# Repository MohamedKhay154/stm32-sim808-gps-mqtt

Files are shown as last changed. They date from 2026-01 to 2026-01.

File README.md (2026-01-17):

# GPS Tracker Using STM32 and SIM808

Embedded IoT tracker based on STM32 and SIM808, providing
GPS positioning, SMS control, and MQTT communication with
a Node-RED backend.

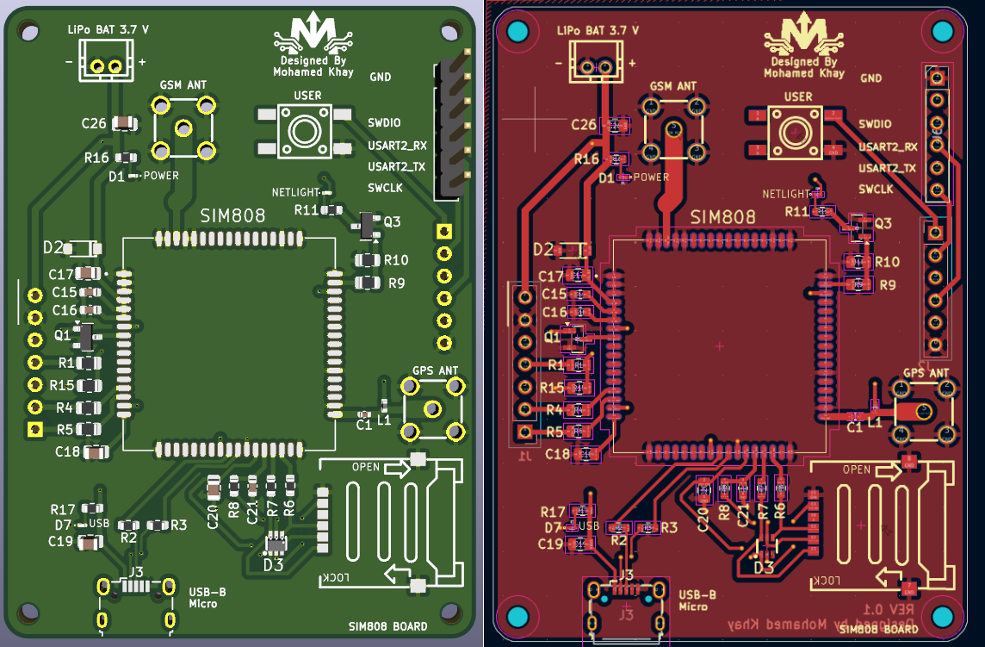
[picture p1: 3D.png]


## Features
- GPS position acquisition (SIM808)
- SMS send / receive
- MQTT communication over GPRS
- Node-RED dashboard integration
- Custom PCB design

## Repository Structure
stm32-sim808-gps-mqtt/

├── firmware/     STM32CubeIDE project

├── PCB Design/   PCB schematics and layout

├── Node-Red/     Node-RED flows and dashboard

├── Docs/         Documentation

├── Images/       Pictures

## System Overview

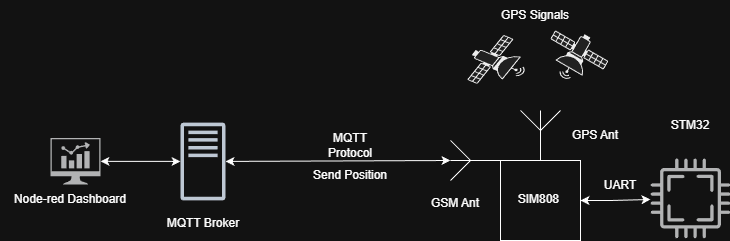
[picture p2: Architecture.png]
Architecture


The STM32 communicates with the SIM808 module via UART.
GPS data is parsed on the MCU and sent either via SMS or
published to an MQTT broker over GPRS. Node-RED processes
incoming data and provides visualization and control.

## PCB Design

The PCB design is divided into two separate boards:

1.One board for the STM32 MCU

2.One board for the SIM808 module

These boards are stacked on top of each other using a common connector interface.

# SIM808 
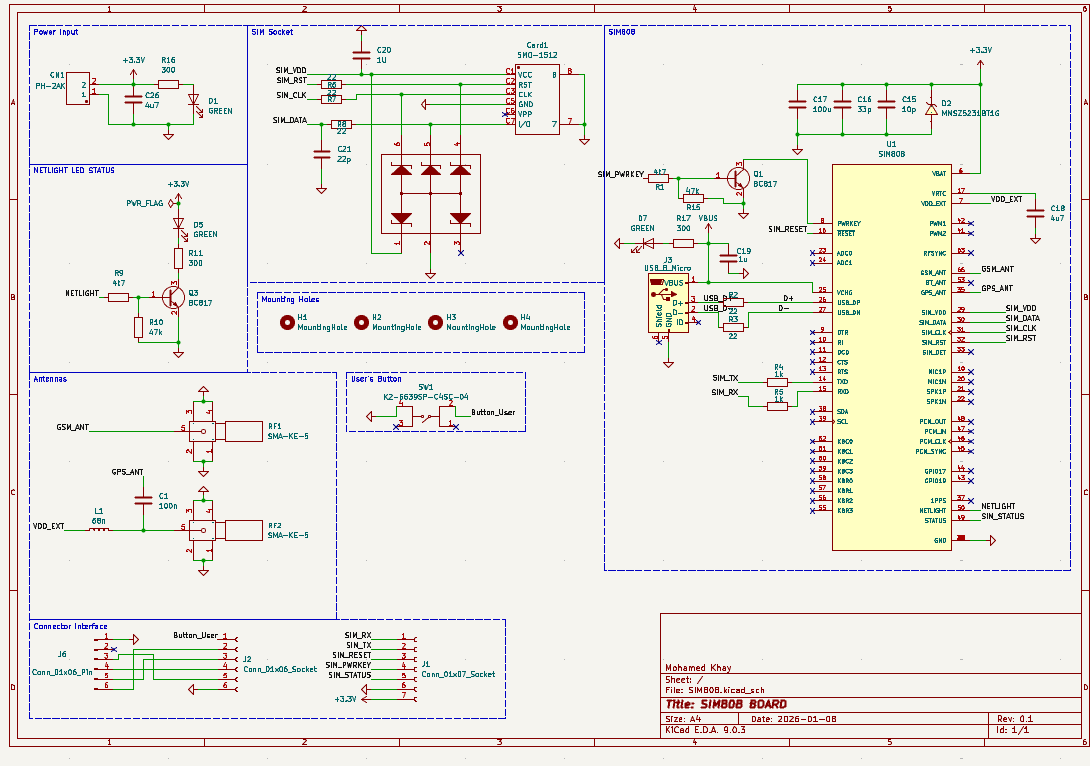
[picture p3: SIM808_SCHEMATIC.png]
SIM808 SCHEMATIC

Notes:

The board uses a LiPo battery as the main power source. The SIM808 module includes an internal charging circuit accessible via USB.

According to the datasheet, when powering the system with a LiPo battery, no additional voltage regulator is needed, provided the battery delivers 3.7 V nominal and 2 A peak.

Both the GPS and GSM antennas require 50 Ω impedance traces and should be placed as close as possible to the module for optimal signal performance.

# STM32 
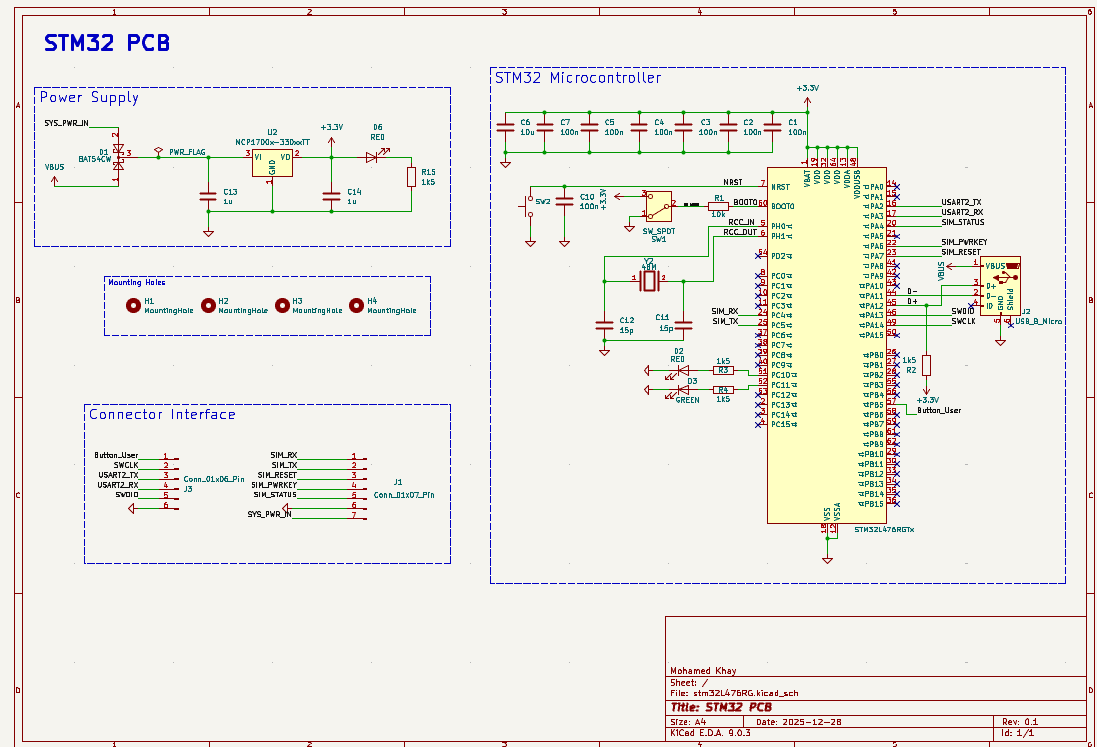
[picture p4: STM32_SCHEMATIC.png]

Notes:

The board uses an MCP1700 voltage regulator to provide stable 3.3 V to the STM32.

There are two power inputs:

1.USB

2.Power from the SIM808 board via a dedicated connector

A Schottky diode is used to prevent backflow and protect the STM32 when multiple power sources are connected.

## Firmware Design

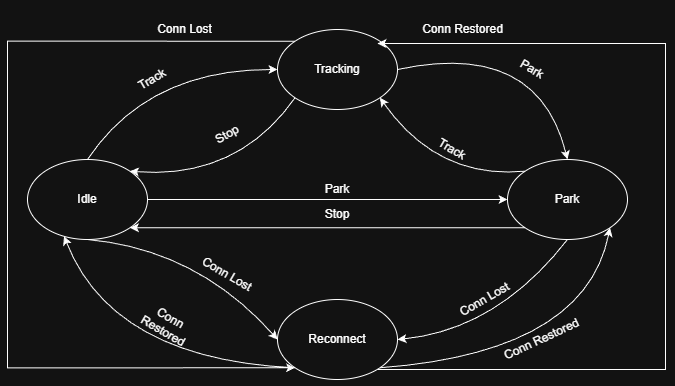
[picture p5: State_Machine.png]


The firmware is structured around a finite state machine (FSM) to securely manage the different operational modes of the module:

- Idle: The module waits for incoming commands or triggers.

- Tracking: Begins continuous position tracking using a timer.

- Parking: Sends the current position and waits for either a “theft move” or “stop” command.

- Reconnect: At any state, if the module detects a disconnection, it transitions to the Reconnect state to re-establish the connection, then returns to the previous state.

Alongside the FSM, a watchdog timer monitors the connection every 30 seconds and attempts to reconnect if needed, ensuring reliable communication.

# Firmware Modules

* SIM808.c
Responsible for all SIM808 communications, including:

- Sending AT commands

- Parsing GPS data

- Handling message transmission and waiting for responses

* MQTT (mqtt.c / mqtt.h)
Implements the MQTT protocol using the Paho MQTT library, helping to build and send MQTT packets.

* tracker_fsm.c
Implements the state machine, including:

- Event handlers
- State transitions

## Node-RED Dashboard

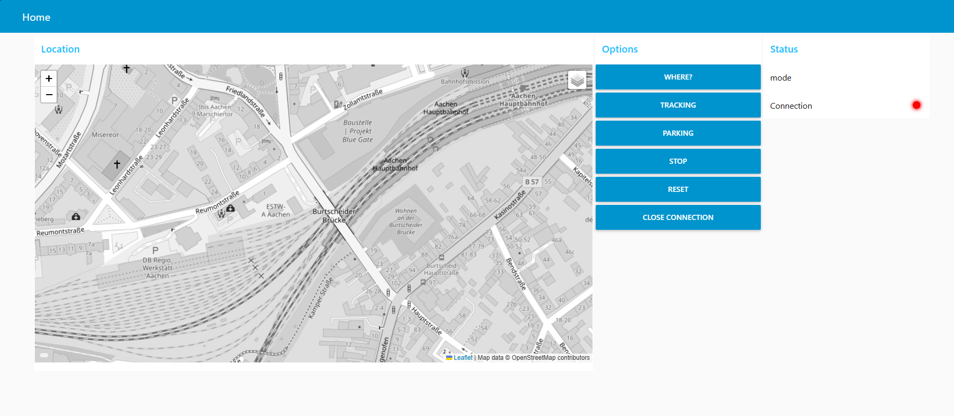
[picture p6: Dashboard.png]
Node Red Dashboard

The dashboard is built using Node-RED and a world map visualization.

Node-RED natively supports MQTT, so once the STM32 firmware publishes a position, the Node-RED flow (as a subscriber) receives it and displays it as a pointer on the map.

Since the system has multiple operational modes (continuous tracking, parking, etc.), a global variable tracks the current mode. This allows the dashboard to adjust the visualization accordingly:

Continuous tracking → plots the path as a line

Parking mode → shows a circle around the parked area

Commands are sent from the dashboard using buttons that publish messages to the MQTT broker. The SIM808 module on the device subscribes to these commands and acts accordingly.

## Further Notes

The project is still under development.

The source code is being updated and may change as new features are added or improvements are made.

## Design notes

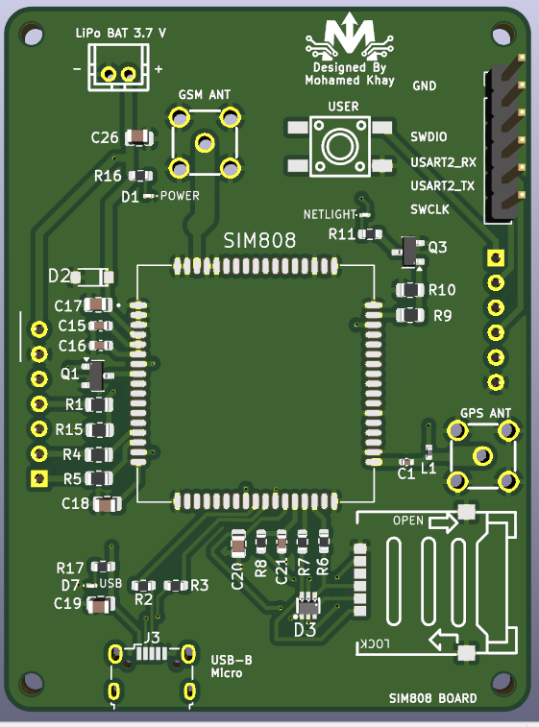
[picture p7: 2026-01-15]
Images/PCB/3D Top SIM808 Board.png

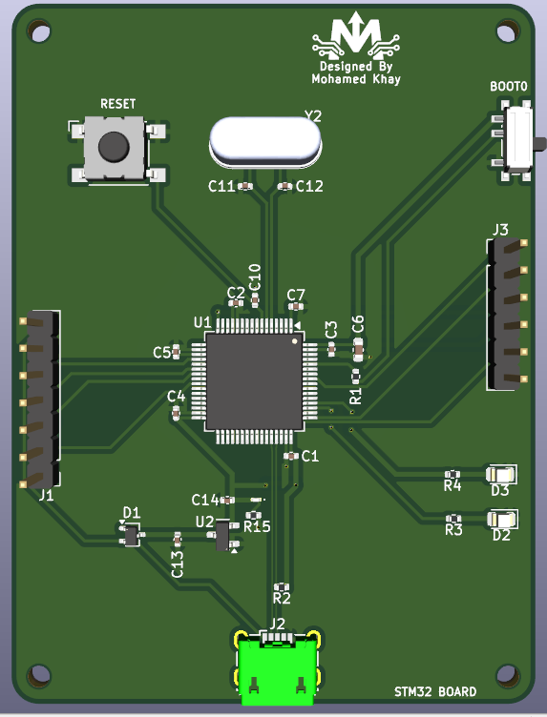
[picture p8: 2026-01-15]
Images/PCB/3D Top STM32 Board.png

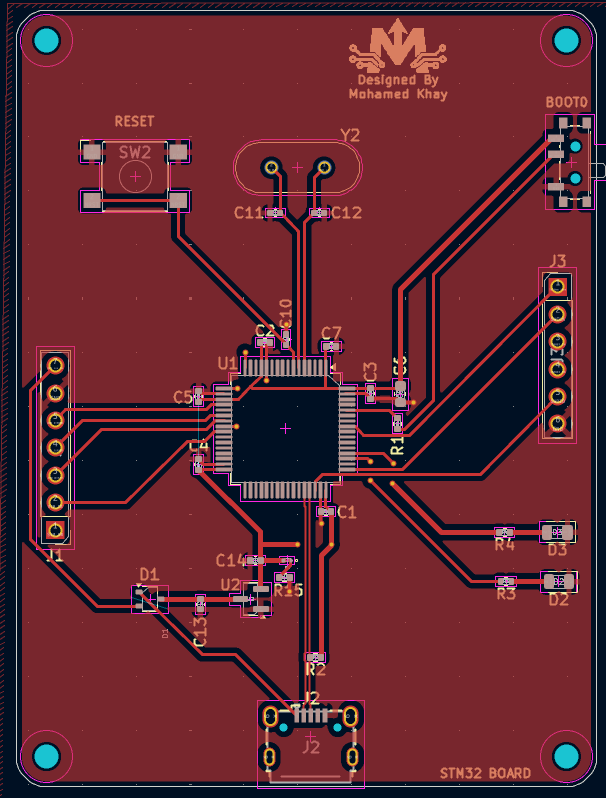
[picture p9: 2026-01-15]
Images/PCB/First Layer STM32 Board.png

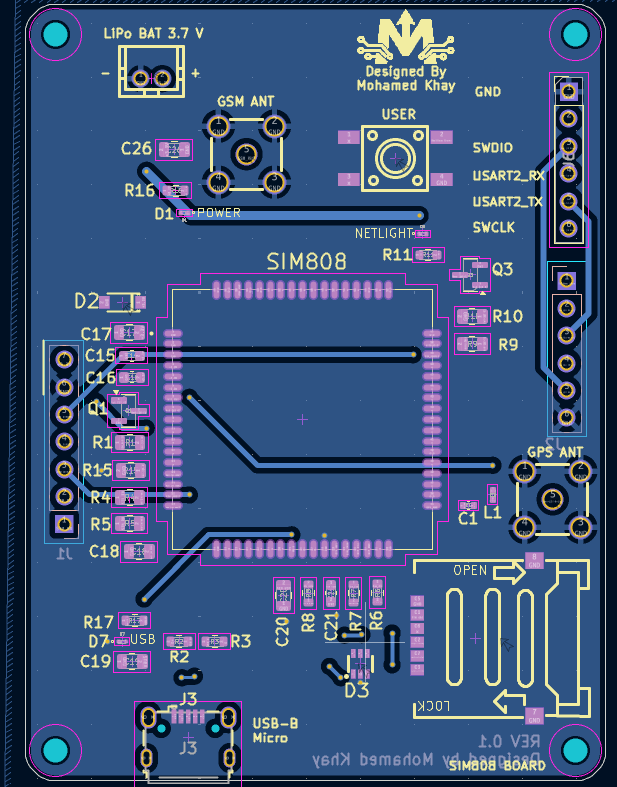
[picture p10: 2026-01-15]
Images/PCB/Second Layer SIM808 Board.png

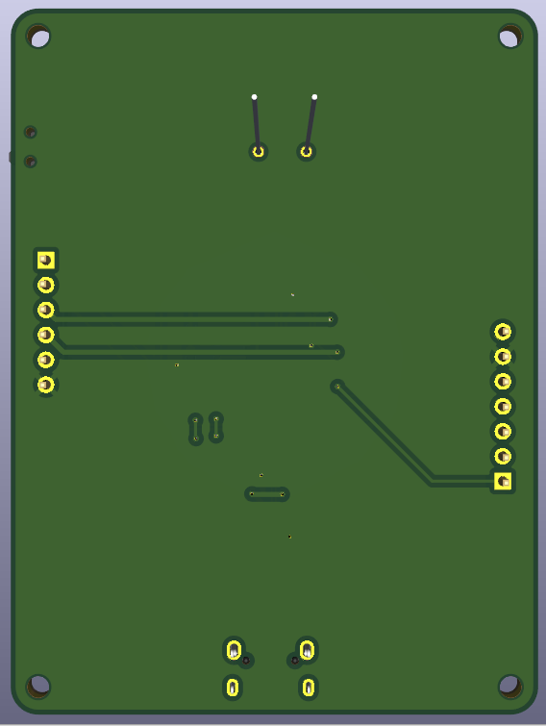
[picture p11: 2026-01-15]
Images/PCB/3D Bottom STM32 Board.png

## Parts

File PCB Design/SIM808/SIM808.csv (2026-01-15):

Reference | Qty | Value | DNP | Exclude from BOM | Exclude from Board | Footprint | Datasheet
C15 | 1 | 10p |  |  |  | Capacitor_SMD:C_0603_1608Metric | ~
C16 | 1 | 33p |  |  |  | Capacitor_SMD:C_0603_1608Metric | ~
C17 | 1 | 100u |  |  |  | Capacitor_SMD:C_0805_2012Metric | ~
C18,C26 | 2 | 4u7 |  |  |  | Capacitor_SMD:C_0805_2012Metric | ~
C19 | 1 | 1u |  |  |  | Capacitor_SMD:C_0805_2012Metric | ~
C20 | 1 | 1U |  |  |  | Capacitor_SMD:C_0805_2012Metric | ~
C21 | 1 | 22p |  |  |  | Capacitor_SMD:C_0603_1608Metric | ~
C22,C23,C24,C25 | 4 | 0 |  |  |  | Capacitor_SMD:C_0603_1608Metric | ~
Card1 | 1 | SMO-1512 |  |  |  | SIM808:SIM_SMD_SMO_1512
CN1 | 1 | JST-PH-2-SMT-RA |  |  |  | SIM808:CONN-SMD_JST-PH-2-SMT-RA
D1,D5,D7 | 3 | GREEN |  |  |  | LED_SMD:LED_0201_0603Metric | ~
D2,D3 | 2 | D_Zener |  |  |  | Diode_SMD:D_0603_1608Metric | ~
D4 | 1 | SMF12CT1G |  |  |  | SIM808:SMF12CT1G
D6 | 1 | MBR0520 |  |  |  | Diode_SMD:D_SOD-123 | http://www.mccsemi.com/up_pdf/MBR0520~MBR0580(SOD123).pdf
H1,H2,H3,H4 | 4 | MountingHole |  | Excluded from BOM |  | MountingHole:MountingHole_2.2mm_M2 | ~
J1 | 1 | Conn_01x07_Socket |  |  |  | Connector_PinSocket_2.54mm:PinSocket_1x07_P2.54mm_Vertical | ~
J2 | 1 | Conn_01x06_Socket |  |  |  | Connector_PinSocket_2.54mm:PinSocket_1x06_P2.54mm_Vertical | ~
J3 | 1 | USB_B_Micro |  |  |  | Connector_USB:USB_Micro-B_Wuerth_629105150521 | ~
J4,J5 | 2 | SMA_CONNECTOR |  |  |  | SMA_CONNECTOR:LPRS_SMA_CONNECTOR
J6 | 1 | Conn_01x06_Pin |  |  |  | Connector_PinHeader_2.54mm:PinHeader_1x06_P2.54mm_Vertical | ~
Q1,Q2 | 2 | 2N3904 |  |  |  | Package_TO_SOT_THT:TO-92_Inline | https://www.onsemi.com/pub/Collateral/2N3903-D.PDF
R1,R9 | 2 | 4k7 |  |  |  | Resistor_SMD:R_0805_2012Metric | ~
R2,R3,R6,R7,R8 | 5 | 22 |  |  |  | Resistor_SMD:R_0603_1608Metric | ~
R4,R5 | 2 | 1k |  |  |  | Resistor_SMD:R_0805_2012Metric | ~
R10,R15 | 2 | 47k |  |  |  | Resistor_SMD:R_0805_2012Metric | ~
R11,R16,R17 | 3 | 300 |  |  |  | Resistor_SMD:R_0603_1608Metric | ~
R12,R13,R14 | 3 | 0 |  |  |  | Resistor_SMD:R_0603_1608Metric | ~
SW1 | 1 | SW_Push |  |  |  | Button_Switch_THT:SW_PUSH_6mm | ~
U1 | 1 | SIM808 |  |  |  | SIM808 (1):XCVR_SIM808

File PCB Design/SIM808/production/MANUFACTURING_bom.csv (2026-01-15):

Designator | Footprint | Quantity | Value | LCSC Part #
C1 | 0402 | 1 | 100n
C15 | 0603 | 1 | 10p
C16 | 0603 | 1 | 33p
C17 | 0805 | 1 | 100u
C18, C26 | 0805 | 2 | 4u7
C19, C20 | 0805 | 2 | 1u
C21 | 0603 | 1 | 22p
CARD1 | SIM_SMD_SMO_1512 | 1 | SMO-1512
CN1 | CONN-TH_PH-2A | 1 | PH-2AK
D1, D5, D7 | 0201 | 3 | GREEN
D2 | SOD-123_L2.8-W1.8-LS3.7-RD | 1 | MMSZ5231BT1G
D3 | SMF12CT1G | 1 | SMF12CT1G
J1 | PinSocket_1x07_P2.54mm_Vertical | 1 | Conn_01x07_Socket
J2 | PinSocket_1x06_P2.54mm_Vertical | 1 | Conn_01x06_Socket
J3 | USB_Micro-B_Wuerth_629105150521 | 1 | USB_B_Micro
J6 | PinHeader_1x06_P2.54mm_Vertical | 1 | Conn_01x06_Pin
L1 | 0402 | 1 | 68n
Q1, Q3 | SOT-23 | 2 | BC817
R1, R9 | 0805 | 2 | 4k7
R10, R15 | 0805 | 2 | 47k
R11, R16, R17 | 0603 | 3 | 300
R2, R3, R6, R7, R8 | 0603 | 5 | 22
R4, R5 | 0805 | 2 | 1k
RF1, RF2 | SMA-TH_SMA-KE-5 | 2 | SMA-KE-5
SW1 | KEY-SMD_4P-L6.0-W6.0-P3.90-LS9.0 | 1 | K2-6639SP-C4SC-04
U1 | XCVR_SIM808 | 1 | SIM808

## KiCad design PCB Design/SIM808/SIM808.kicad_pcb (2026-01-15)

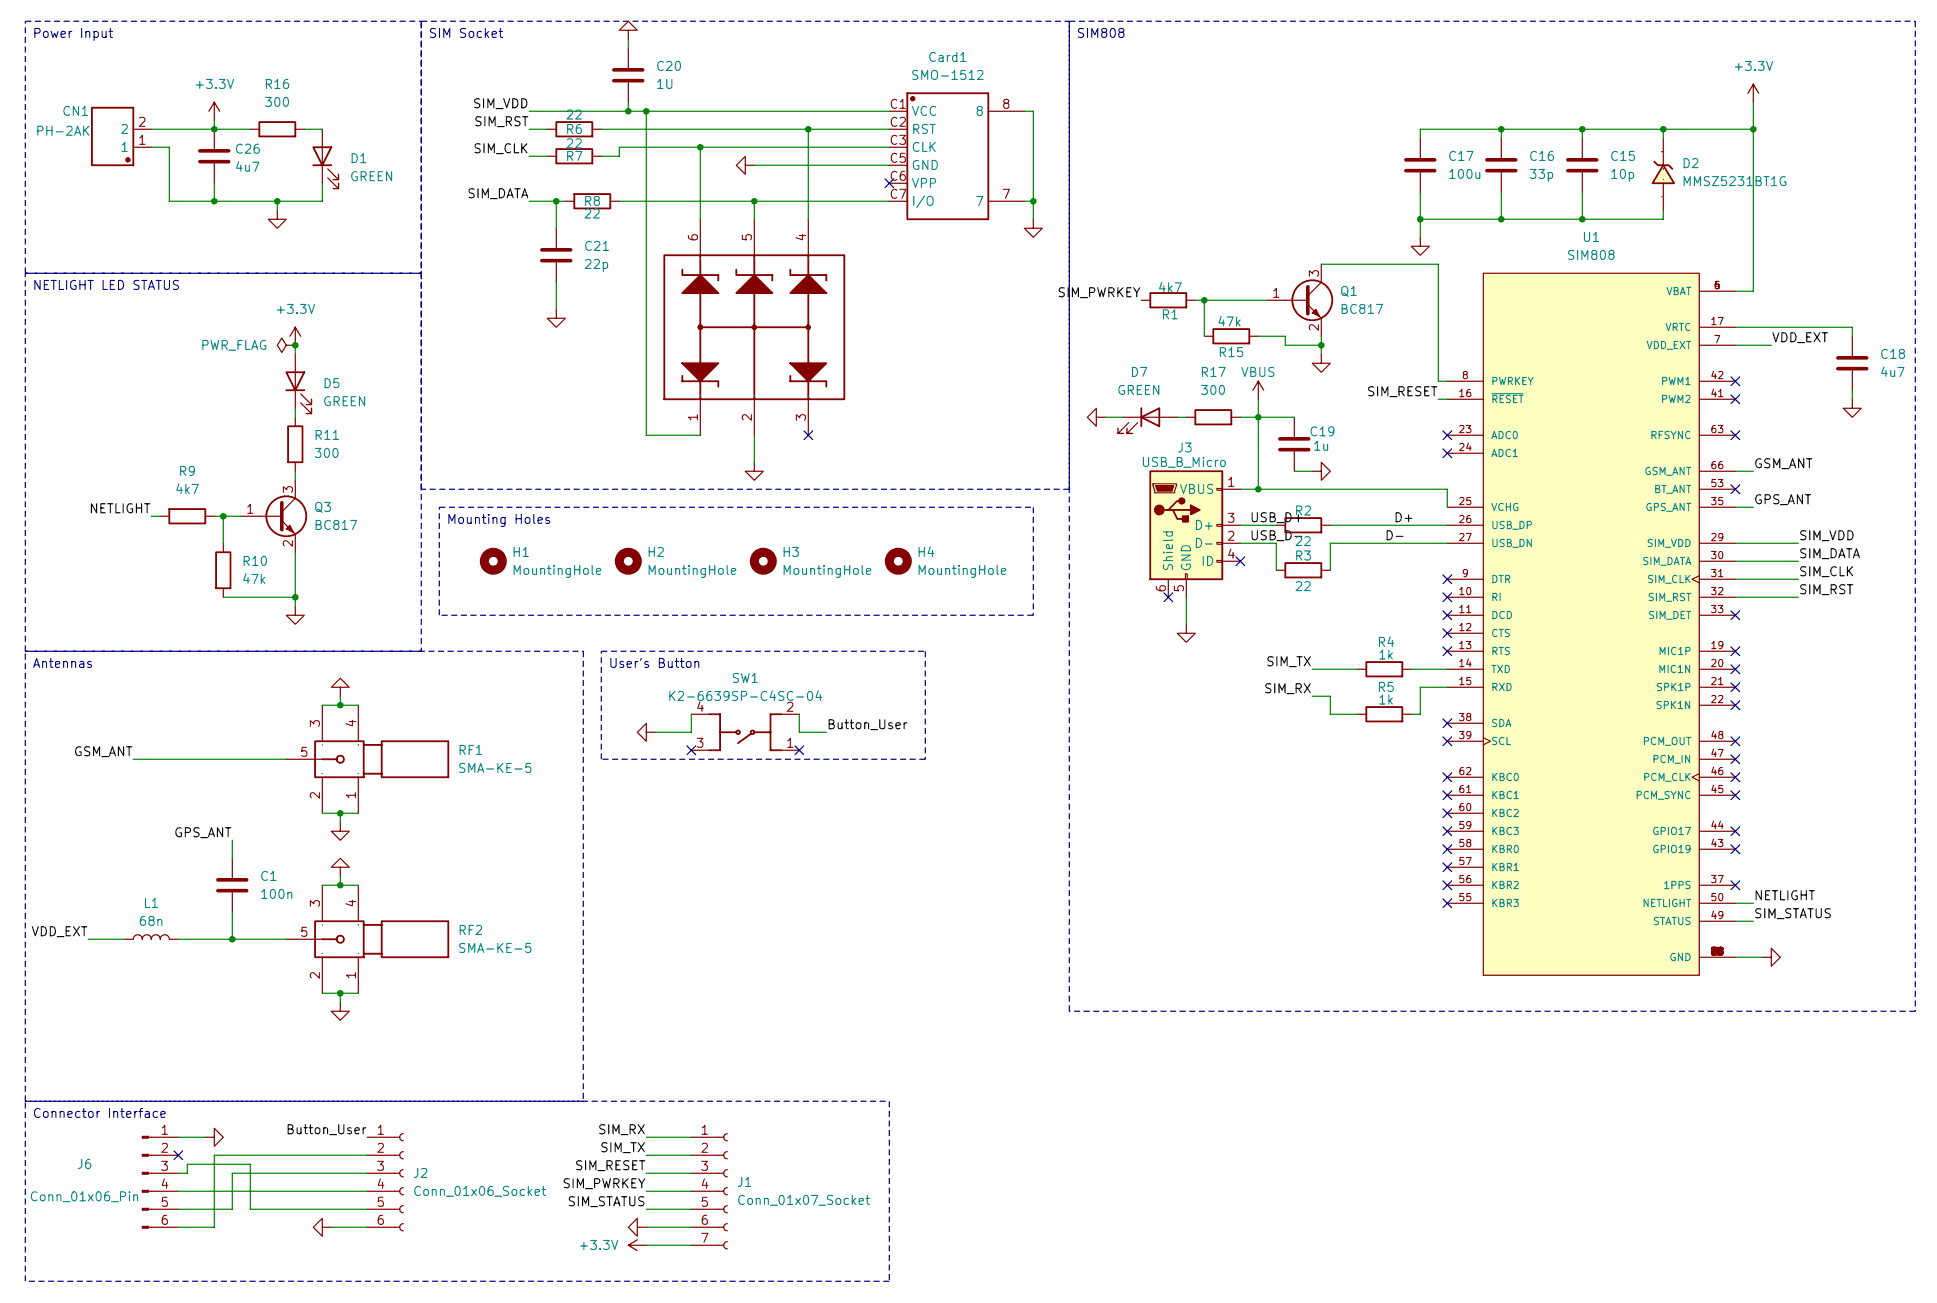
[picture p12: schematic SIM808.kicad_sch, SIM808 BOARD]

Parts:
C1: 100n; C_0402_1005Metric
C15: 10p; C_0603_1608Metric
C16: 33p; C_0603_1608Metric
C17: 100u; C_0805_2012Metric
C18, C26: 4u7; C_0805_2012Metric
C19: 1u; C_0805_2012Metric
C20: 1U; C_0805_2012Metric
C21: 22p; C_0603_1608Metric
CN1: PH-2AK; CONN-TH_PH-2A; Manufacturer Part PH-2AK
Card1: SMO-1512; SIM_SMD_SMO_1512; Manufacturer Part SMO-1512
D1, D5, D7: GREEN; LED_0201_0603Metric
D2: MMSZ5231BT1G; SOD-123_L2.8-W1.8-LS3.7-RD; Manufacturer Part MMSZ5231BT1G
D3: SMF12CT1G; Manufacturer Part SMF12CT1G
H1, H2, H3, H4: MountingHole; MountingHole_2.2mm_M2
J1: Conn_01x07_Socket; PinSocket_1x07_P2.54mm_Vertical
J2: Conn_01x06_Socket; PinSocket_1x06_P2.54mm_Vertical
J3: USB_B_Micro; USB_Micro-B_Wuerth_629105150521
J6: Conn_01x06_Pin; PinHeader_1x06_P2.54mm_Vertical
L1: 68n; L_0402_1005Metric
Q1, Q3: BC817; SOT-23
R1, R9: 4k7; R_0805_2012Metric
R2, R3, R6, R7, R8: 22; R_0603_1608Metric
R4, R5: 1k; R_0805_2012Metric
R10, R15: 47k; R_0805_2012Metric
R11, R16, R17: 300; R_0603_1608Metric
RF1, RF2: SMA-KE-5; SMA-TH_SMA-KE-5; Manufacturer Part SMA-KE-5
SW1: K2-6639SP-C4SC-04; KEY-SMD_4P-L6.0-W6.0-P3.90-LS9.0; Manufacturer Part K2-6639SP-C4SC-04
U1: SIM808; XCVR_SIM808; PARTREV 1.03

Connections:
+3.3V: C15.2, C16.2, C17.2, C26.2, CN1.2, D2.1 (K), D5.2 (A), J1.7, R16.1, U1.4 (VBAT), U1.5 (VBAT), U1.6 (VBAT)
/Button_User: J2.1, SW1.2
/D+: R2.2, U1.26 (USB_DP)
/D-: R3.2, U1.27 (USB_DN)
/GPS_ANT: C1.1, U1.35 (GPS_ANT)
/GSM_ANT: RF1.5, U1.66 (GSM_ANT)
/NETLIGHT: R9.2, U1.50 (NETLIGHT)
/SIM_CLK: R7.1, U1.31 (SIM_CLK)
/SIM_DATA: C21.1, R8.2, U1.30 (SIM_DATA)
/SIM_PWRKEY: J1.4, R1.1
/SIM_RESET: J1.3, U1.16 (~RESET)
/SIM_RST: R6.1, U1.32 (SIM_RST)
/SIM_RX: J1.1, R5.1
/SIM_STATUS: J1.5, U1.49 (STATUS)
/SIM_TX: J1.2, R4.1
/SIM_VDD: C20.2, Card1.C1 (VCC), D3.1, U1.29 (SIM_VDD)
/USB_D+: J3.3 (D+), R2.1
/USB_D-: J3.2 (D-), R3.1
/VDD_EXT: L1.1, U1.7 (VDD_EXT)
GND: C15.1, C16.1, C17.1, C18.1, C19.1, C20.1, C21.2, C26.1, CN1.1, Card1.7, Card1.8, Card1.C5 (GND), D1.1 (K), D2.2 (A), D3.2, D7.1 (K), J1.6, J2.6, J3.5 (GND), J6.1, Q1.2 (E), Q3.2 (E), R10.2, R15.2, RF1.1, RF1.2, RF1.3, RF1.4, RF2.1, RF2.2, RF2.3, RF2.4, SW1.4, U1.1 (GND), U1.2 (GND), U1.3 (GND), U1.18 (GND), U1.28 (GND), U1.34 (GND), U1.36 (GND), U1.40 (GND), U1.51 (GND), U1.52 (GND), U1.54 (GND), U1.64 (GND), U1.65 (GND), U1.67 (GND), U1.68 (GND)
unnamed: C1.2, L1.2, RF2.5
unnamed: Card1.C3 (CLK), D3.6, R7.2
unnamed: Card1.C7 (I/O), D3.5, R8.1
unnamed: Card1.C2 (RST), D3.4, R6.2
unnamed: D1.2 (A), R16.2
unnamed: D5.1 (K), R11.1
unnamed: D7.2 (A), R17.1
unnamed: J2.2, J6.6
unnamed: J2.3, J6.5
unnamed: J2.4, J6.4
unnamed: J2.5, J6.3
unnamed: Q1.1 (B), R1.2, R15.1
unnamed: Q1.3 (C), U1.8 (PWRKEY)
unnamed: Q3.1 (B), R9.1, R10.1
unnamed: Q3.3 (C), R11.2
unnamed: R5.2, U1.15 (RXD)
unnamed: R4.2, U1.14 (TXD)
unnamed: C18.2, U1.17 (VRTC)
VBUS: C19.2, J3.1 (VBUS), R17.2, U1.25 (VCHG)

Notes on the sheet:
User's Button
Mounting Holes
NETLIGHT LED STATUS
Connector Interface
Power Input
Antennas
SIM808
SIM Socket

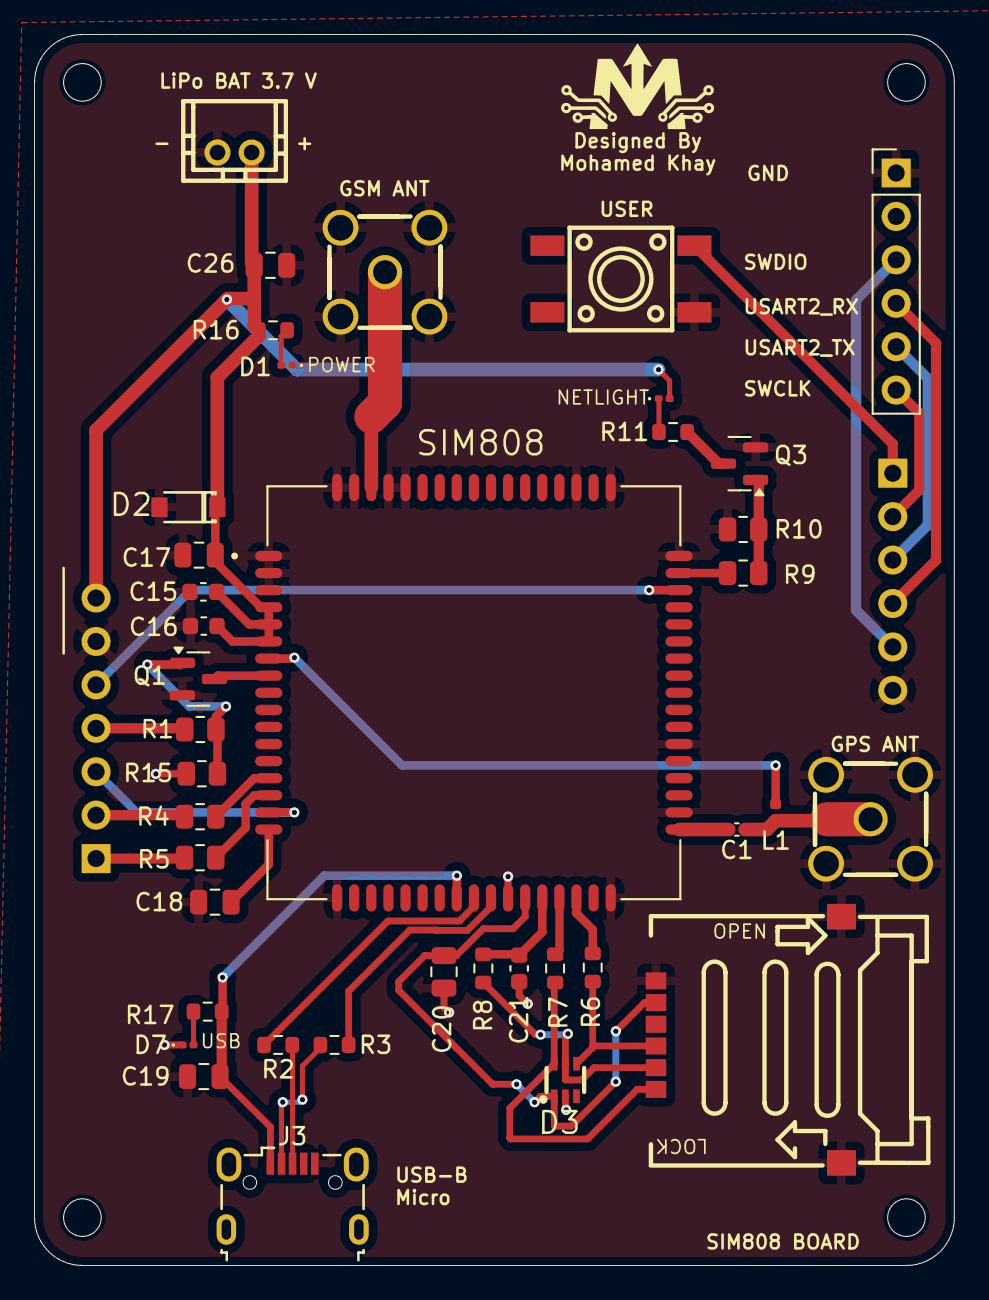
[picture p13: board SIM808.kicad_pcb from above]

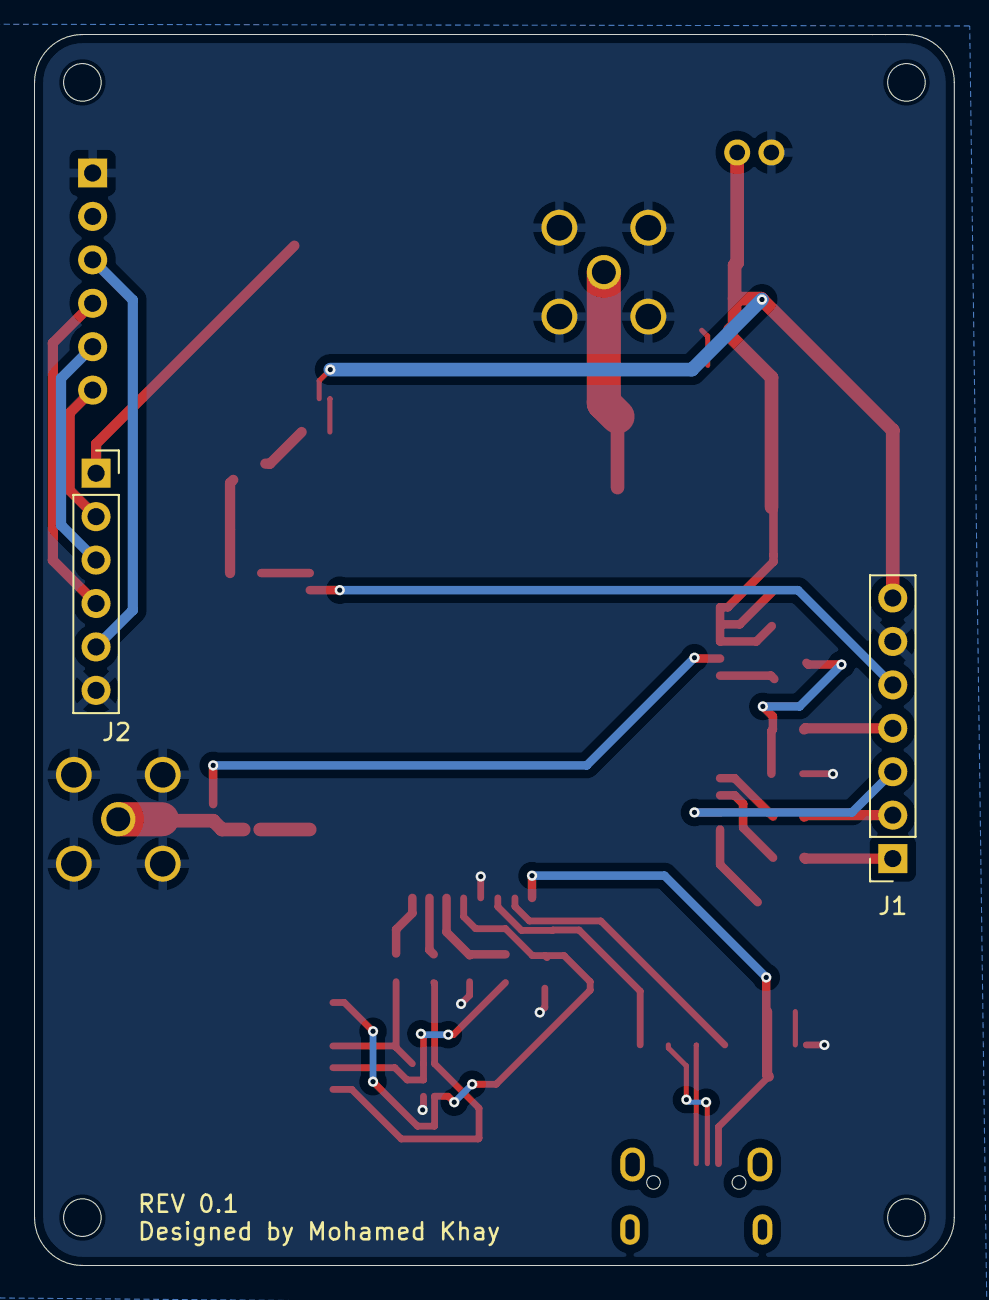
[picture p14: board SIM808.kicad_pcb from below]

Board: 2 copper layers, 53.8 x 72.0 mm, 45 parts (2 on the bottom side), 39 nets.

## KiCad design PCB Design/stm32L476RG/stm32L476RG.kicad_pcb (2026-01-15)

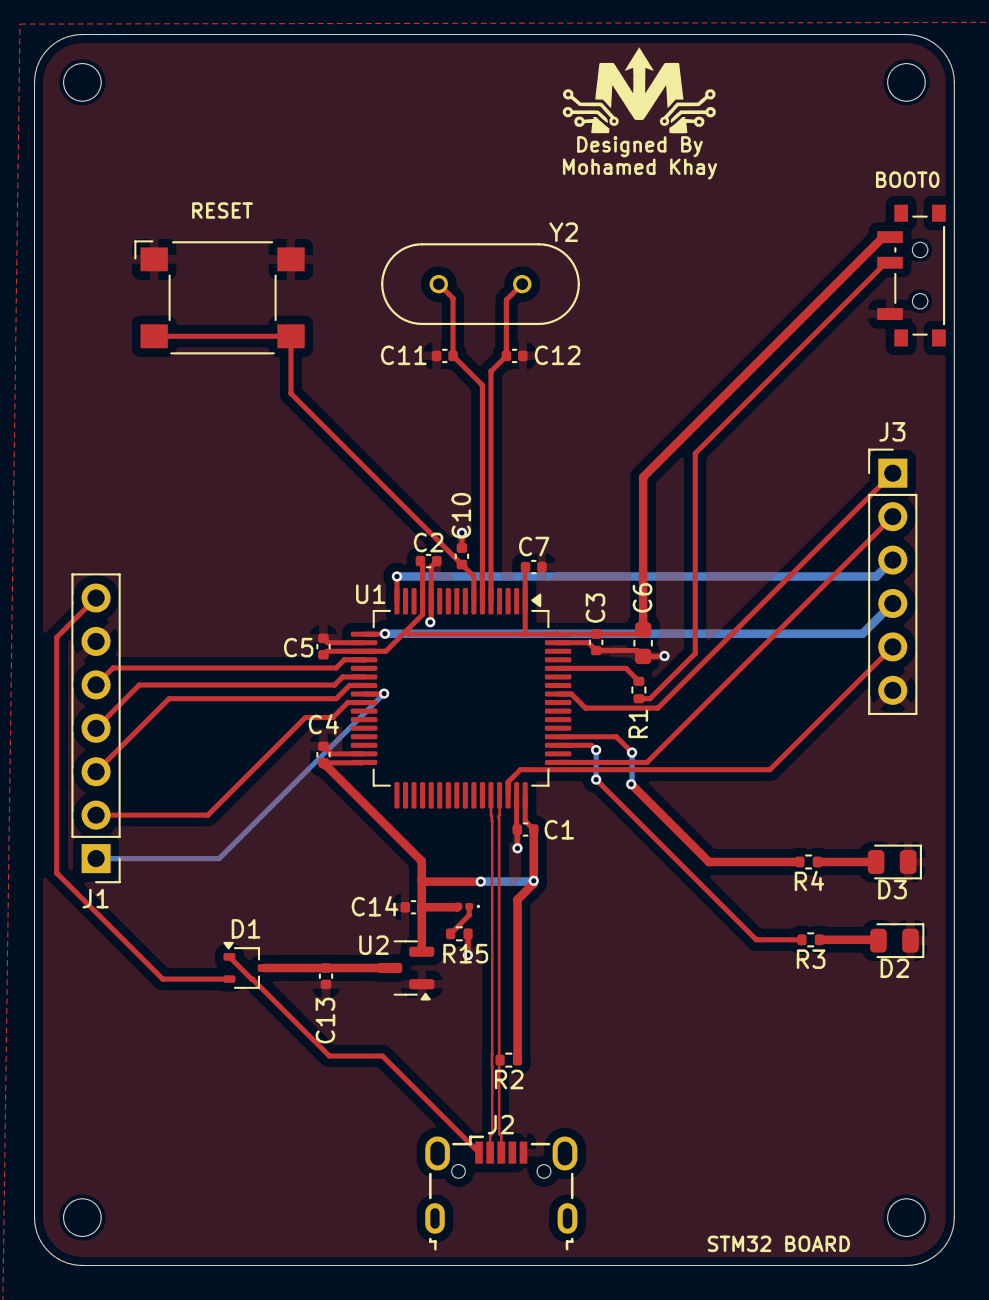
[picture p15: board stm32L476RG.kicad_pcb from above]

Board: 2 copper layers, 53.8 x 72.0 mm, 33 parts (0 on the bottom side), 27 nets.

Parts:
C1, C2, C3, C4, C5, C7, C10: 100n; C_0402_1005Metric
C6: 10u; C_0603_1608Metric
C11, C12: 15p; C_0402_1005Metric
C13, C14: 1u; C_0402_1005Metric
D1: BAT54CW; SOT-323_SC-70
D2: RED; LED_0805_2012Metric
D3: GREEN; LED_0805_2012Metric
D6: RED; LED_0201_0603Metric
H1, H2, H3, H4: MountingHole; MountingHole_2.2mm_M2
J1: Conn_01x07_Pin; PinHeader_1x07_P2.54mm_Vertical
J2: USB_B_Micro; USB_Micro-B_Wuerth_629105150521
J3: Conn_01x06_Pin; PinHeader_1x06_P2.54mm_Vertical
R1: 10k; R_0402_1005Metric
R2, R3, R4, R15: 1k5; R_0402_1005Metric
SW1: SW_SPDT; SW_SPDT_PCM12_NO_TIP
SW2: SW_Omron_B3FS; SW_SPST_Omron_B3FS-100xP
U1: STM32L476RGTx; LQFP-64_10x10mm_P0.5mm
U2: MCP1700x-330xxTT; SOT-23
Y2: 48M; XTAL_HC49P488W43L1150T466H350

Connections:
+3.3V: C1.1, C2.1, C3.1, C4.1, C5.1, C6.1, C7.1, C14.1, D6.2 (A), R2.1, SW1.3 (C), U1.1 (VBAT), U1.13 (VDDA), U1.19 (VDD), U1.32 (VDD), U1.48 (VDDUSB), U1.64 (VDD), U2.2 (VO)
/BOOT0: R1.2, U1.60 (BOOT0)
/Button_User: J3.1, U1.57 (PB5)
/D+: J2.3 (D+), R2.2, U1.45 (PA12)
/D-: J2.2 (D-), U1.44 (PA11)
/NRST: C10.1, SW2.2, U1.7 (NRST)
/RCC_IN: C12.1, U1.5 (PH0), Y2.1
/RCC_OUT: C11.1, U1.6 (PH1), Y2.2
/SIM_PWRKEY: J1.4, U1.22 (PA6)
/SIM_RESET: J1.3, U1.23 (PA7)
/SIM_RX: J1.1, U1.24 (PC4)
/SIM_STATUS: J1.5, U1.20 (PA4)
/SIM_TX: J1.2, U1.25 (PC5)
/SWCLK: J3.2, U1.49 (PA14)
/SWDIO: J3.5, U1.46 (PA13)
/SW_BOOT0: R1.1, SW1.2 (B)
/SYS_PWR_IN: D1.2, J1.7
/USART2_RX: J3.4, U1.17 (PA3)
/USART2_TX: J3.3, U1.16 (PA2)
GND: C1.2, C2.2, C3.2, C4.2, C5.2, C6.2, C7.2, C10.2, C11.2, C12.2, C13.2, C14.2, D2.1 (K), D3.1 (K), J1.6, J2.5 (GND), J3.6, R15.2, SW1.1 (A), SW2.1, U1.12 (VSSA), U1.18 (VSS), U1.31 (VSS), U1.47 (VSS), U1.63 (VSS), U2.1 (GND)
unnamed: D2.2 (A), R3.1
unnamed: D3.2 (A), R4.1
unnamed: D6.1 (K), R15.1
unnamed: R3.2, U1.51 (PC10)
unnamed: R4.2, U1.52 (PC11)
unnamed: C13.1, D1.3, U2.3 (VI)
VBUS: D1.1, J2.1 (VBUS)

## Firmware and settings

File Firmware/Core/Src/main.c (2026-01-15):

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
/* Includes ------------------------------------------------------------------*/
#include "main.h"

/* USER CODE BEGIN Includes */
#include "timer.h"
#include "tarcker_fsm.h"

#include <stdint.h>
#include <stdbool.h>
/* USER CODE END Includes */

TIM_HandleTypeDef htim2;
TIM_HandleTypeDef htim3;

UART_HandleTypeDef huart2;
UART_HandleTypeDef huart3;

void SystemClock_Config(void);
static void MX_GPIO_Init(void);
static void MX_USART2_UART_Init(void);
static void MX_USART3_UART_Init(void);
static void MX_TIM2_Init(void);
static void MX_TIM3_Init(void);
/**
  * @brief  The application entry point.
  * @retval int
  */
int main(void)
{

  /* MCU Configuration--------------------------------------------------------*/

  /* Reset of all peripherals, Initializes the Flash interface and the Systick. */
  HAL_Init();

  /* Configure the system clock */
  SystemClock_Config();

  /* Initialize all configured peripherals */
  MX_GPIO_Init();
  MX_USART2_UART_Init();
  MX_USART3_UART_Init();
  MX_TIM2_Init();
  MX_TIM3_Init();
  /* USER CODE BEGIN 2 */
  WatchdogTimer_Start();
  State_Idle_Enter();
  initReceive();
  /* USER CODE END 2 */

  /* Infinite loop */
  /* USER CODE BEGIN WHILE */
while (1) {

		Event_t ev = Event_Wait();
		//HAL_Delay(1000);

		if (ev == EVENT_NONE) {
			continue;
		}

		switch (current_state) {

		case STATE_IDLE:
			State_Idle_HandleEvent(ev);
			break;

		case STATE_TRACKING:
			State_Tracking_HandleEvent(ev);
			break;

		case STATE_PARK:
			State_Park_HandleEvent(ev);
			break;

		case STATE_RECONNECT:
			State_Reconnect_HandleEvent(ev);
			break;
		}

    /* USER CODE END WHILE */

    /* USER CODE BEGIN 3 */
  }
  /* USER CODE END 3 */
}

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


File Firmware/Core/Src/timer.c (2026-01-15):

/*
 * timer.c
 *
 *  Created on: Dec 22, 2025
 *      Author: Mohamed
 */


#include "timer.h"
#include "stm32l4xx_hal.h"

extern TIM_HandleTypeDef htim2;
extern TIM_HandleTypeDef htim3; // CubeMX generated timer


static volatile bool track_timer_flag = false;
static volatile bool watchdog_timer_flag = false;

/**
 * @brief Start the timer
 * @param period_sec Tracking period in seconds
 */
void TrackTimer_Start(uint32_t period_sec)
{
    uint32_t base_freq = 10000; // 10 kHz timer base (PSC = 8399)
    uint32_t arr = period_sec * base_freq - 1;

    __HAL_TIM_DISABLE(&htim2);
    __HAL_TIM_SET_AUTORELOAD(&htim2, arr);
    __HAL_TIM_SET_COUNTER(&htim2, 0);
    HAL_TIM_Base_Start_IT(&htim2);

    track_timer_flag = false;
}

/**
 * @brief Stop the timer
 */
void TrackTimer_Stop(void)
{
    HAL_TIM_Base_Stop_IT(&htim2);
    track_timer_flag = false;
}

/**
 * @brief Check and consume pending timer event
 * @return true if event pending, false otherwise
 */
bool TrackTimer_EventPending(void)
{
    if (track_timer_flag) {
        track_timer_flag = false;
        return true;
    }
    return false;
}

/**
 * @brief Start the timer
 * @param period_sec Tracking period in seconds
 */
void WatchdogTimer_Start()
{
    /*uint32_t base_freq = 10000; // 10 kHz timer base (PSC = 8399)
    uint32_t arr = period_sec * base_freq - 1;

    __HAL_TIM_DISABLE(&htim3);
    __HAL_TIM_SET_AUTORELOAD(&htim3, arr);
    __HAL_TIM_SET_COUNTER(&htim3, 0);
    */
    HAL_TIM_Base_Start_IT(&htim3);

    watchdog_timer_flag = false;
}

/**
 * @brief Stop the timer
 */
void WatchdogTimer_Stop(void)
{
    HAL_TIM_Base_Stop_IT(&htim3);
    watchdog_timer_flag = false;
}

/**
 * @brief Check and consume pending timer event
 * @return true if event pending, false otherwise
 */
bool WatchdogTimer_EventPending(void)
{
    if (watchdog_timer_flag) {
    	watchdog_timer_flag = false;
        return true;
    }
    return false;
}

/**
 * @brief To be called from HAL_TIM_PeriodElapsedCallback
 */
void HAL_TIM_PeriodElapsedCallback(TIM_HandleTypeDef *htim)
{
    if (htim->Instance == TIM2) {
    	track_timer_flag = true; // signal event to FSM
    }
    if (htim->Instance == TIM3) {
    	watchdog_timer_flag = true; // signal event to FSM
        }
}

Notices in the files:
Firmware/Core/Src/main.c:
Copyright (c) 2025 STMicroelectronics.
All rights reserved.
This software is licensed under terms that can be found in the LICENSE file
